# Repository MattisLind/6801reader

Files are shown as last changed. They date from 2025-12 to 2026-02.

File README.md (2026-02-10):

# 6801reader
This project aims at reading the ROM content out of a mask programmed MC6801 uP used in the Ericsson PC keyboard.

Ericsson PC keyboard

To help the MAME project to create a faithful emulation of the Ericsson PC I was asked to dump the ROM contents of a mask programmed 
6801 uProcessor which is the brain inside the keyboard. Compared to standard IBM PC the Ericsson PC make use of a completely different keyboard protocol
The protocol has standard serial communication rather than the clocked shiftregister approach in the IBM PC. In the receiving end on the mainboard there is a 8251 
serial communication IC. Dumping the keyboard and then emulating the MC6801 uProcessor inside MAME would then give a complete and faithful emulation of 
thenentire Ericsson PC.

## Dumping the 6801
Masked ROM can be a bit tricky to read out. On some uProcessor it isn't possible at all. On the 6801 there is a test mode 0 which 
makes the processor to behave a bit odd. It sets  the processor in non multiplexed mode which means that the 8 IO ports are the upper 8 bits of the address.
Then another IO port is the multiplexed Data and Adress bus for the lower 8 bits of the address. This is quite standard, but there
is another tweak that makes it possible to do the reading. In mode 0 it will also read the RESET vector from the external bus. It will disable reading
of the internal ROM for the two first cycles, thereby allowing external logic to map in external ROM for these two cycles and have the 
processor start the external program.

The external program can then be used to read all of the internal memory. Including the RESET vectors since after the two first access the internal address decoding goes back to
normal and the internal ROM RESET vectors can be read.

## Design

Adress decoding need special treatment during the first two cycles. This is achieved by a shiftregister that is shifting the RESET
signal when it transits from active to inactive. The three stage shiftregister is clocked by the negative edge of the E signal.
The result will be a delayed RESET signal. As long as the delayed RESET signal is low the deccoding will map addresses in the F800-FFFF range to
the external EPROM. After this period this decoding will be disabled and only accesses to F000-F7FF will be decoded as external.

The logic to handle the decoding and the shiftregister is implemented in a GAL16V8 PLD. The PLD also is used to debounce the RESET 
signal from the toggle switch.

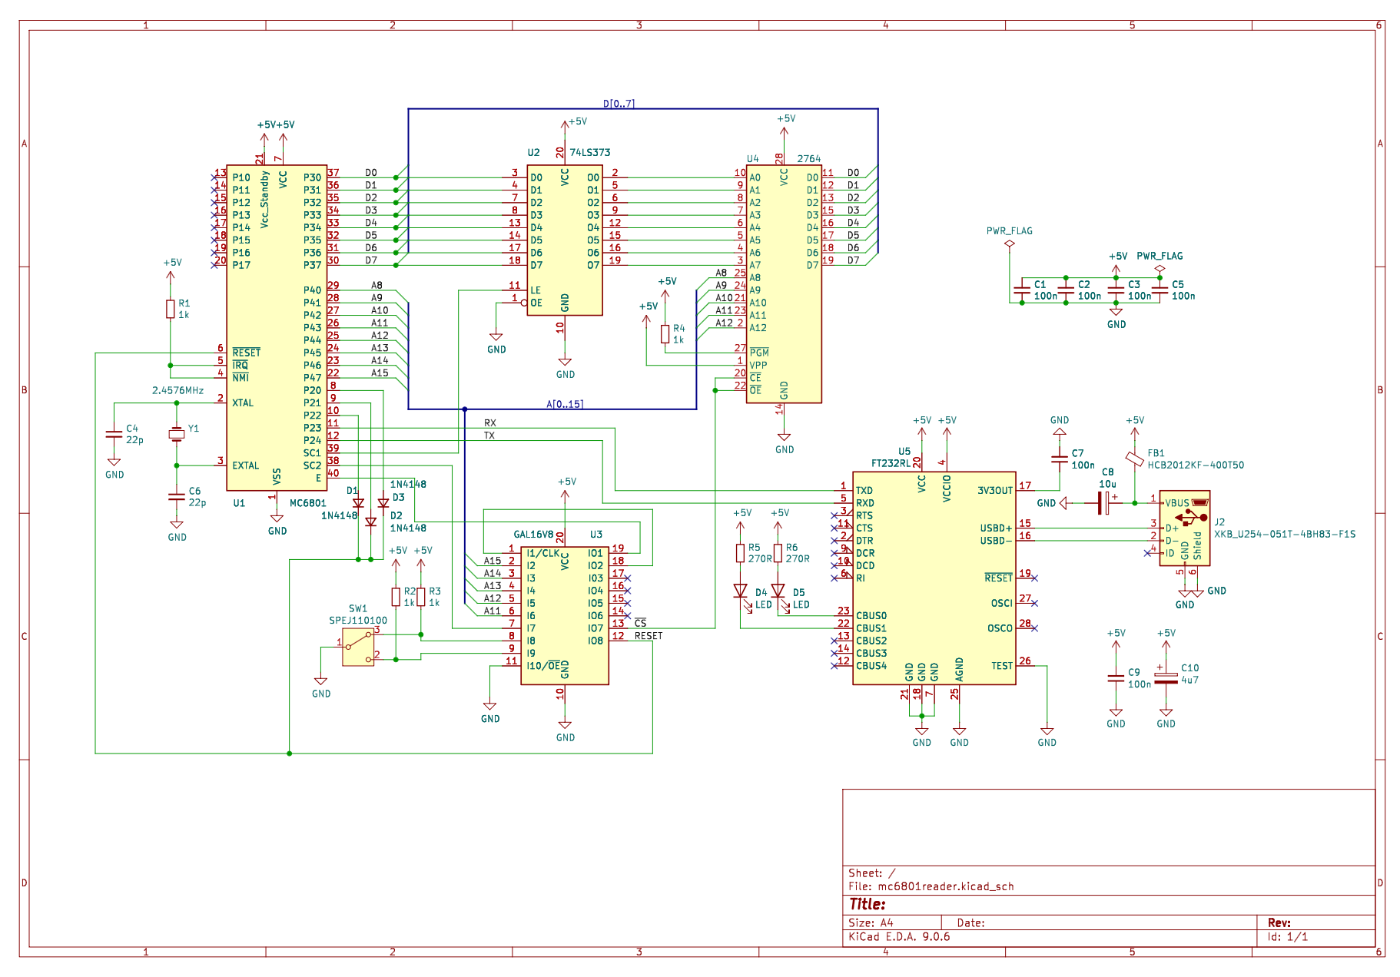
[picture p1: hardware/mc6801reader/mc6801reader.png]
Schematic


## Firmware

The firmware used is a small debug monitor developed by Daniel Tufvesson [called MC3 monitor](http://www.waveguide.se/?article=mc3-monitor-13) which is modified 
to handle different memory locations for ROM and RAM. The 2.4576 MHz crystal result in a 4800 bps rate of the serial port.

The monitor can then be used to dump the ROM contents and transfer it to the host PC over the serial port.

The 2764 is a 8k EPROM with total address range 0000-1FFF.
This means that the 2k monitor code need to be in BOTH the 1000-17FF range and the 1800-1FFF range for the design to work. I.e. during the first two cycles it will access the 1800-1FFF range and after that the 1000-17FF range will be accessed. Actually repeating the monitor on all four 2k banks of the EPROM wouldn't harm at all. The PLD will select the proper range.

## Schemtic and layout.

A schematic has been created in KiCAD and a breadboard circuit. Possibly a layout is created as well.

## Mockup 

Schematic

A mockup was created on a breadboard and a small problem was detected in the PLD. New PLD code fixed that problem. It was also detected that 68701 is sufficently different from the 6801 to not work with this circuit. The reason is that the 68701 has the interrupt vectors in a different place when running in mode 0. The 6803, which is the romless variant of the 6801, does work identical to the 6801. As it turns out it works perfectly with the circuit above. One interesting thing is that there actually are ROM content in the ROM which seems to be at least potentially correct. At least the RESET vector is in the correct spot! So it seems the 6803 is just 6801 chips which has been discarded due to bad firmware!? 

With the baudrate set to 4800 bps a 6803 or a 6801 processor gave us a ">" prompt in response to pressing the reset button. It was working! 

Schematic

The resulting dump of the Ericsson keyboard 6801 firmware contained some interesting strings!

Schematic

## PCB layout

A modified design and PCB layout were created with KiCad 9.0. The main change was to add a FT232 USB to serial IC. Additionally, A11 was reconnected to the EPROM, requiring the ROM to be put in all four banks as suggested above.

(modified design and layout by Tom Virostek (xuulan))

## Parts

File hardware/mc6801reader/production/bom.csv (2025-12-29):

Designator | Footprint | Quantity | Value | LCSC Part #
C1, C2, C3, C5, C7, C9 | 0805 | 6 | 100n
C10 | CP_EIA-3216-18_Kemet-A | 1 | 4u7
C4, C6 | 0805 | 2 | 22p
C8 | CP_EIA-3216-18_Kemet-A | 1 | 10u
D1, D2, D3 | D_SOD-323 | 3 | 1N4148
D4, D5 | 0805 | 2 | LED
FB1 | 0805 | 1 | HCB2012KF-400T50
J2 | USB_Micro-B_XKB_U254-051T-4BH83-F1S | 1 | XKB_U254-051T-4BH83-F1S
R1, R2, R3, R4 | 0805 | 4 | 1k
R5, R6 | 0805 | 2 | 270R
SW1 | SPEJ110100 | 1 | SPEJ110100
U1 | DIP-40_W15.24mm | 1 | MC6801
U2 | SOIC-20W_7.5x12.8mm_P1.27mm | 1 | 74LS373
U3 | DIP-20_W7.62mm_Socket | 1 | GAL16V8
U4 | DIP-28_W15.24mm | 1 | 2764
U5 | SSOP-28_5.3x10.2mm_P0.65mm | 1 | FT232RL
Y1 | Crystal_HC49-U_Vertical | 1 | 2.4576MHz

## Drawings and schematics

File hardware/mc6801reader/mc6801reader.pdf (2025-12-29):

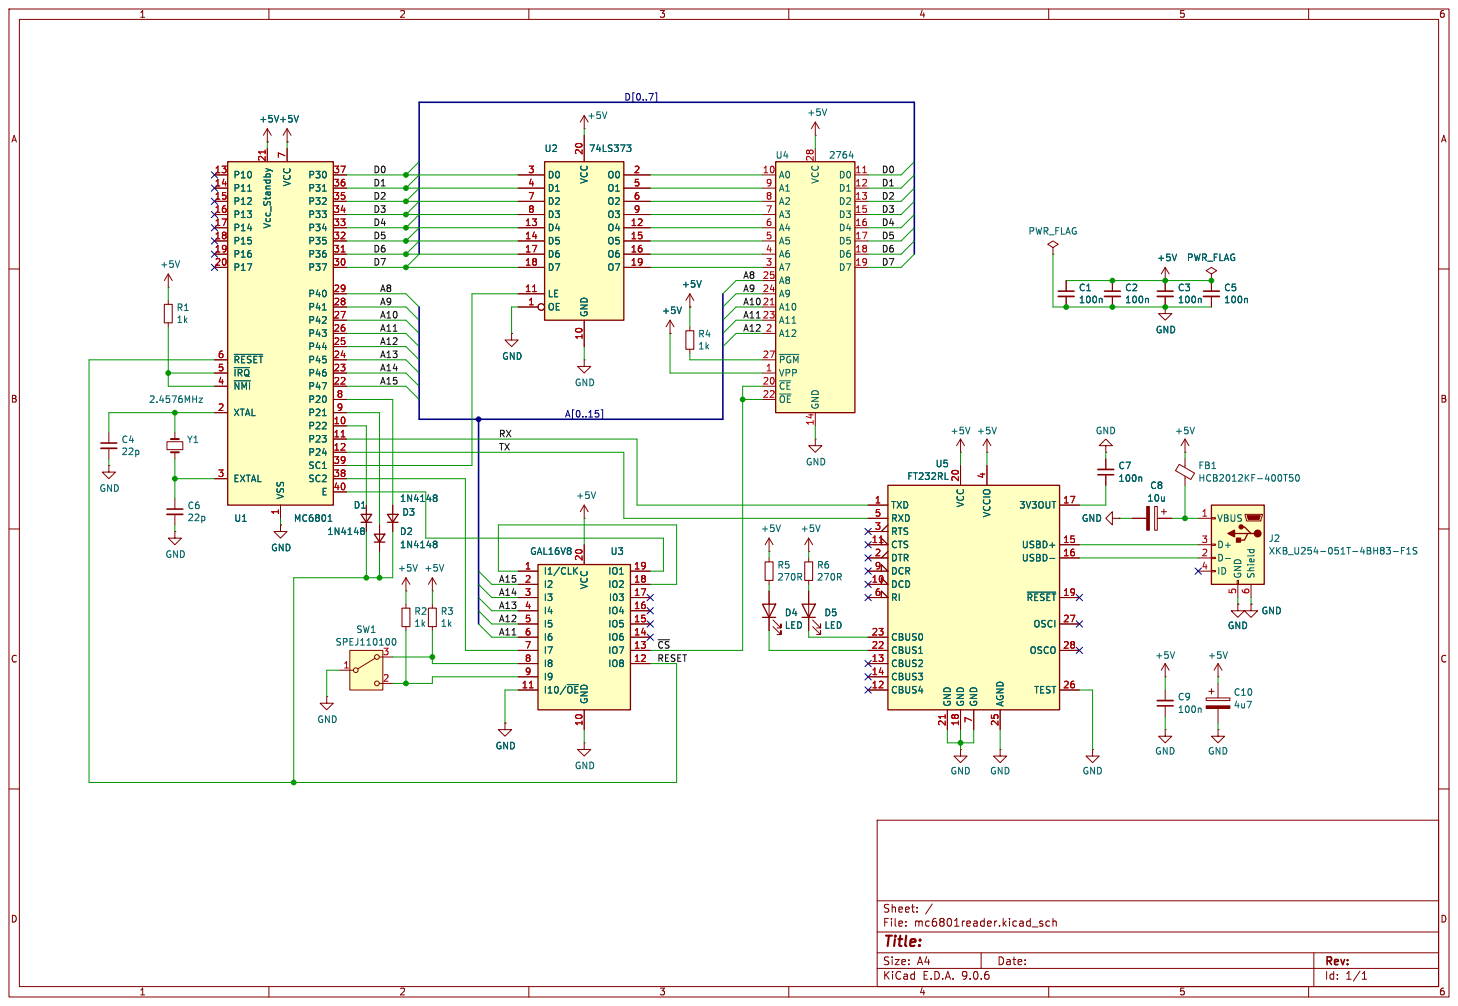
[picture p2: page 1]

7 VCC 20 GND 18 GND 21 TXD 1 RXD 5 RTS 3 CTS 11 DTR 2 DCR 9 DCD 10 RI 6 CBUS0 23 CBUS1 22 CBUS2 13 CBUS3 14 CBUS4 12 U5 FT232RL D1

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

Id: 1/1 Title: File: mc6801reader.kicad_sch Sheet: / C6

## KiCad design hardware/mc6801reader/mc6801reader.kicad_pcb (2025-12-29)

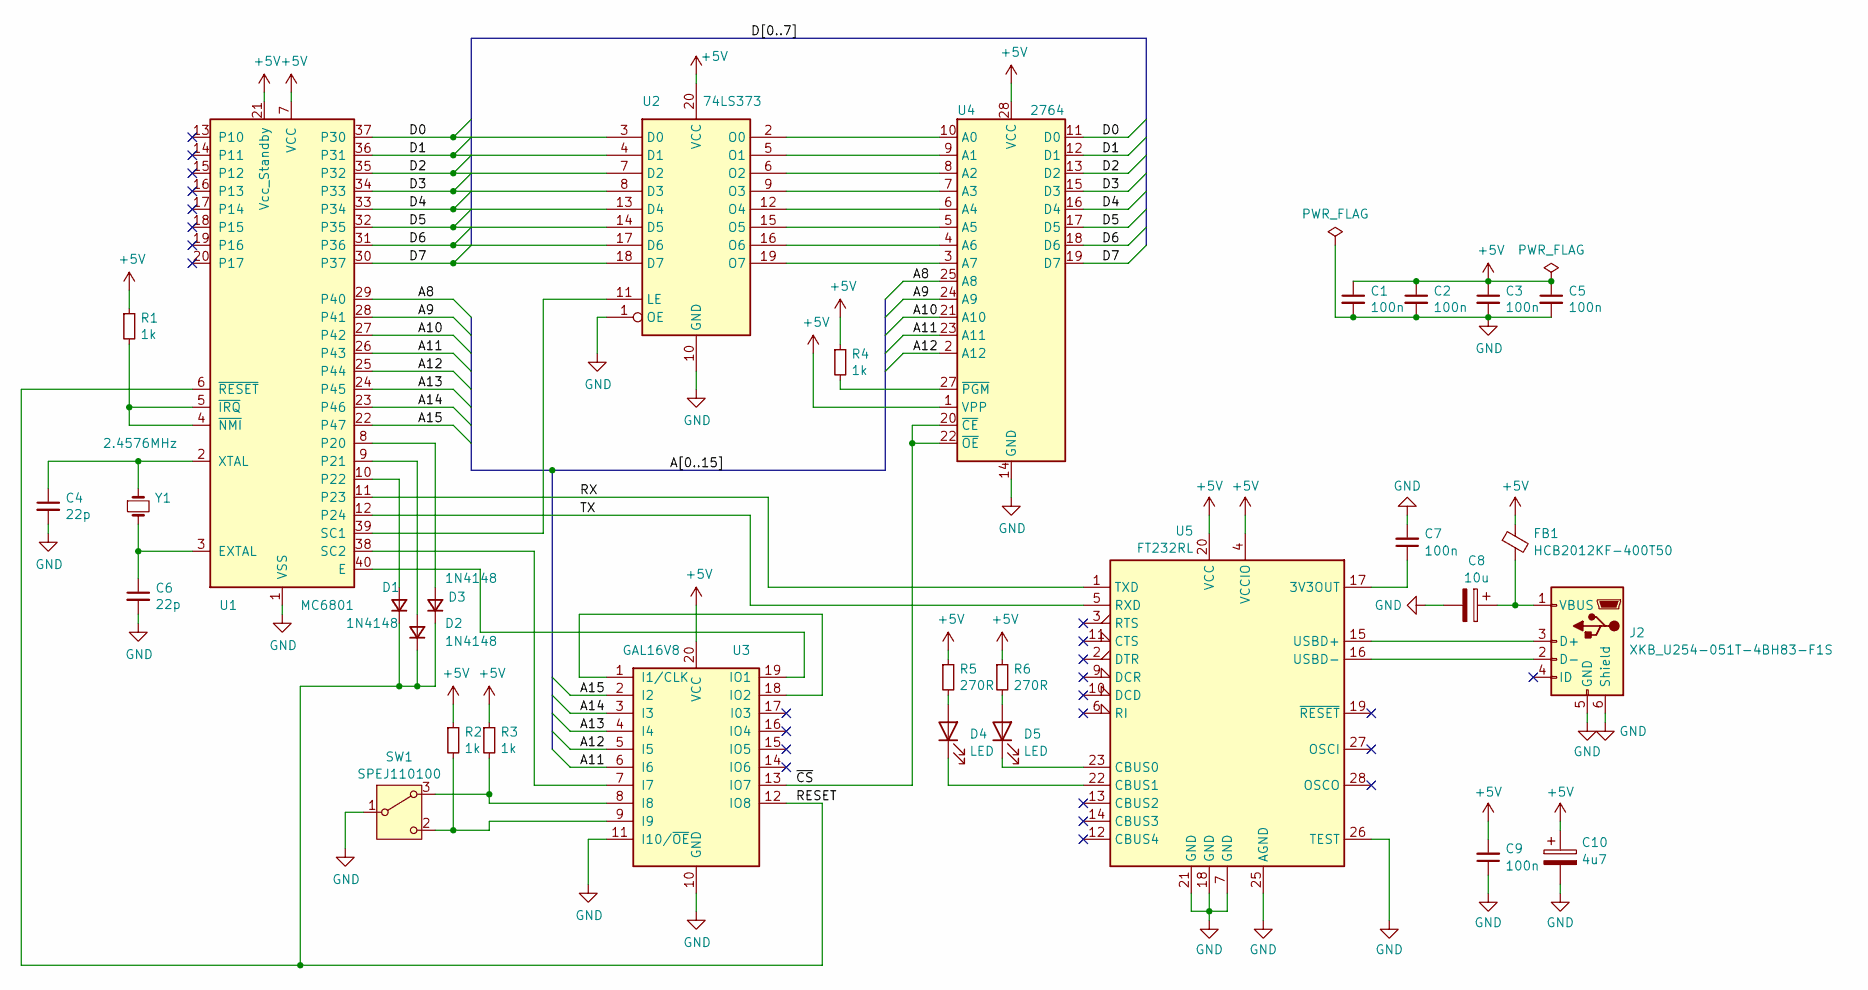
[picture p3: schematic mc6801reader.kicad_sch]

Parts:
C1, C2, C3, C5, C7, C9: 100n; C_0805_2012Metric
C4, C6: 22p; C_0805_2012Metric
C8: 10u; CP_EIA-3216-18_Kemet-A
C10: 4u7; CP_EIA-3216-18_Kemet-A
D1, D2, D3: 1N4148; D_SOD-323
D4, D5: LED; LED_0805_2012Metric
FB1: HCB2012KF-400T50; L_0805_2012Metric
J2: XKB_U254-051T-4BH83-F1S; USB_Micro-B_XKB_U254-051T-4BH83-F1S
R1, R2, R3, R4: 1k; R_0805_2012Metric
R5, R6: 270R; R_0805_2012Metric
SW1: SPEJ110100
U1: MC6801; DIP-40_W15.24mm
U2: 74LS373; SOIC-20W_7.5x12.8mm_P1.27mm
U3: GAL16V8; DIP-20_W7.62mm_Socket
U4: 2764; DIP-28_W15.24mm
U5: FT232RL; SSOP-28_5.3x10.2mm_P0.65mm
Y1: 2.4576MHz; Crystal_HC49-U_Vertical

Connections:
+5V: C1.1, C2.1, C3.1, C5.1, C9.2, C10.1, FB1.1, R1.1, R2.1, R3.1, R4.1, R5.1, R6.1, U1.7 (VCC), U1.21 (Vcc_Standby), U2.20 (VCC), U3.20 (VCC), U4.1 (VPP), U4.28 (VCC), U5.4 (VCCIO), U5.20 (VCC)
/A8: U1.29 (P40), U4.25 (A8)
/A9: U1.28 (P41), U4.24 (A9)
/A10: U1.27 (P42), U4.21 (A10)
/A11: U1.26 (P43), U3.6 (I6), U4.23 (A11)
/A12: U1.25 (P44), U3.5 (I5), U4.2 (A12)
/A13: U1.24 (P45), U3.4 (I4)
/A14: U1.23 (P46), U3.3 (I3)
/A15: U1.22 (P47), U3.2 (I2)
/D0: U1.37 (P30), U2.3 (D0), U4.11 (D0)
/D1: U1.36 (P31), U2.4 (D1), U4.12 (D1)
/D2: U1.35 (P32), U2.7 (D2), U4.13 (D2)
/D3: U1.34 (P33), U2.8 (D3), U4.15 (D3)
/D4: U1.33 (P34), U2.13 (D4), U4.16 (D4)
/D5: U1.32 (P35), U2.14 (D5), U4.17 (D5)
/D6: U1.31 (P36), U2.17 (D6), U4.18 (D6)
/D7: U1.30 (P37), U2.18 (D7), U4.19 (D7)
/RESET: D1.1 (K), D2.1 (K), D3.1 (K), U1.6 (~RESET), U3.12 (IO8)
/RX: U1.11 (P23), U5.1 (TXD)
/TX: U1.12 (P24), U5.5 (RXD)
/~CS: U3.13 (IO7), U4.20 (~CE), U4.22 (~OE)
GND: C1.2, C2.2, C3.2, C4.2, C5.2, C6.2, C7.2, C8.2, C9.1, C10.2, J2.5 (GND), J2.6 (Shield), SW1.1 (B), U1.1 (VSS), U2.1 (OE), U2.10 (GND), U3.10 (GND), U3.11 (I10/~OE), U4.14 (GND), U5.7 (GND), U5.18 (GND), U5.21 (GND), U5.25 (AGND), U5.26 (TEST)
unnamed: D1.2 (A), U1.10 (P22)
unnamed: D2.2 (A), U1.9 (P21)
unnamed: D3.2 (A), U1.8 (P20)
unnamed: D4.2 (A), R5.2
unnamed: D4.1 (K), U5.22 (CBUS1)
unnamed: D5.2 (A), R6.2
unnamed: D5.1 (K), U5.23 (CBUS0)
unnamed: J2.3 (D+), U5.15 (USBD+)
unnamed: J2.2 (D-), U5.16 (USBD-)
unnamed: C8.1, FB1.2, J2.1 (VBUS)
unnamed: R3.2, SW1.3 (A), U3.8 (I8)
unnamed: R2.2, SW1.2 (C), U3.9 (I9)
unnamed: U1.40 (E), U3.19 (IO1)
unnamed: C6.1, U1.3 (EXTAL), Y1.2
unnamed: U1.39 (SC1), U2.11 (LE)
unnamed: U1.38 (SC2), U3.7 (I7)
unnamed: C4.1, U1.2 (XTAL), Y1.1
unnamed: R1.2, U1.4 (~NMI), U1.5 (~IRQ)
unnamed: U2.2 (O0), U4.10 (A0)
unnamed: U2.5 (O1), U4.9 (A1)
unnamed: U2.6 (O2), U4.8 (A2)
unnamed: U2.9 (O3), U4.7 (A3)
unnamed: U2.12 (O4), U4.6 (A4)
unnamed: U2.15 (O5), U4.5 (A5)
unnamed: U2.16 (O6), U4.4 (A6)
unnamed: U2.19 (O7), U4.3 (A7)
unnamed: U3.1 (I1/CLK), U3.18 (IO2)
unnamed: R4.2, U4.27 (~PGM)
unnamed: C7.1, U5.17 (3V3OUT)

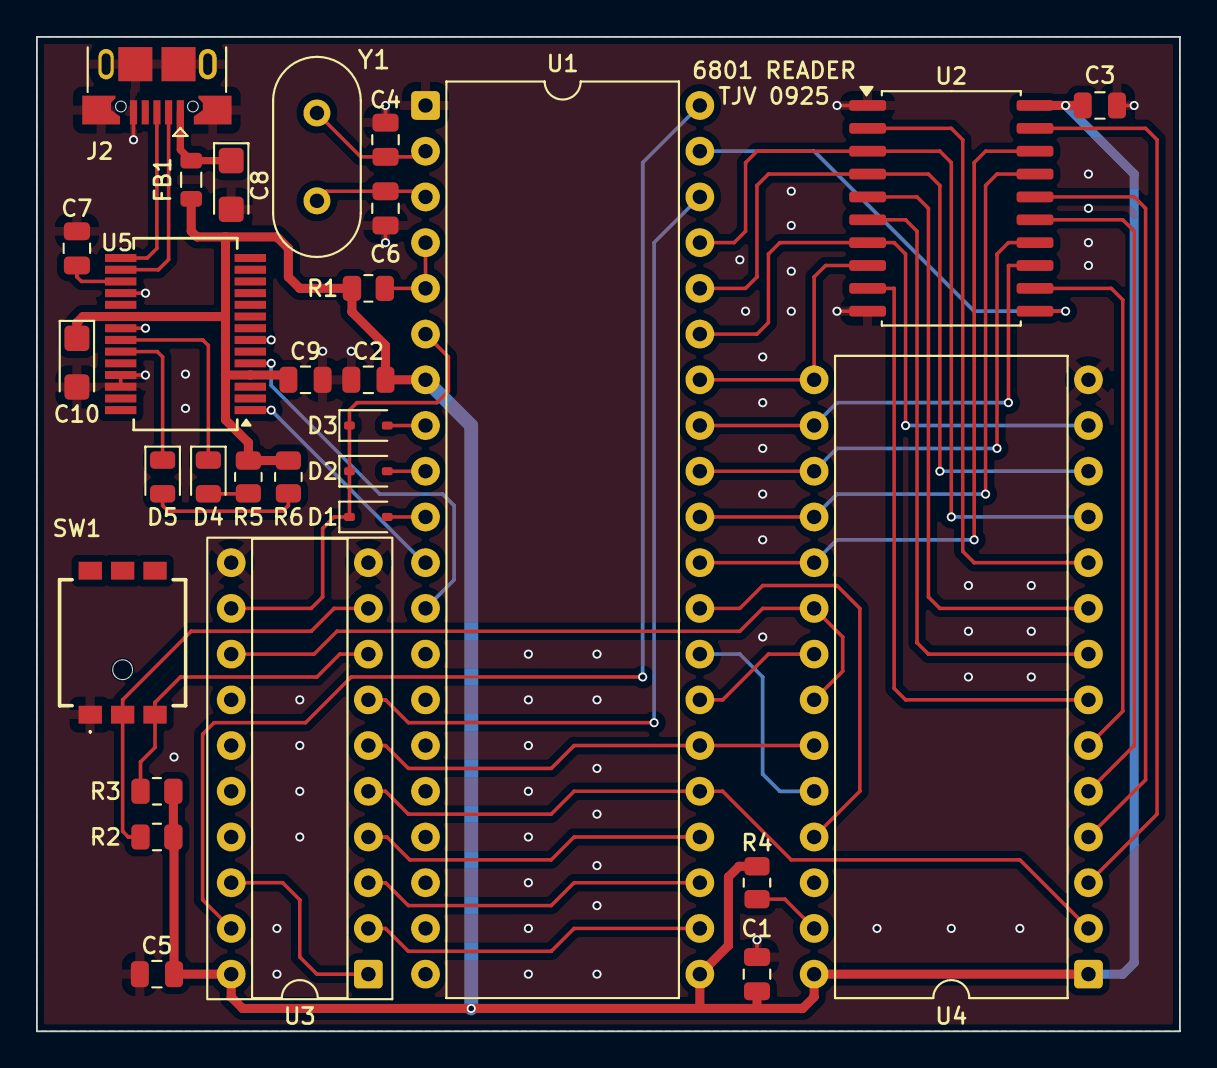
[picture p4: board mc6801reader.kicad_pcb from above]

Board: 2 copper layers, 63.5 x 55.2 mm, 30 parts (0 on the bottom side), 51 nets.

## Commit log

2019-08-29 First draft of design of hardware
    [mc6801reader.kicad_pcb, mc6801reader.sch]
2019-08-29 Added pdf file for the schematic.
2019-08-29 Added schematic
2019-08-29 Now the right schematic instead.
2019-08-30 initial commit of 68xx cross assembler suite
2019-09-07 Updated schematic to reflect changes in PLD code
    [mc6801reader.sch]
2019-09-07 Updated readme with new schematic, added pictures.
2019-09-11 A11 is grounded
    [mc6801reader.kicad_pcb, mc6801reader.sch]
2025-12-29 Modify design and create PCB layout.
    [bom.csv, designators.csv, mc6801reader.kicad_pcb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]
2026-02-10 Fix schematic image link in README
    Updated schematic image link in README.
